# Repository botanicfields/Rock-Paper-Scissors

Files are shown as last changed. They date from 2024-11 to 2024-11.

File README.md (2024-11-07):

# Rock-Paper-Scissors
This is a beginner-friendly craft kit used at DIY events as a material for hands-on soldering.  
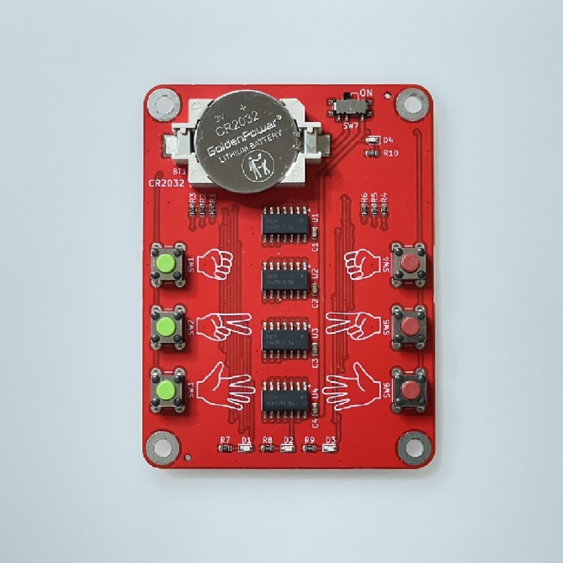
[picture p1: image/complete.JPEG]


# じゃんけん判定器キット
- 初級用のはんだ付け教材を想定した電子工作キットです。  
- 地域イベントなどで、電子工作のはんだ付け体験（ハンズオン）に利用できます。  
- 不特定の来場者が短時間の参加で完成できる様、はんだ付け個所を24と少なくしています。  
- 難易度を下げるため、取り付ける部品はタクトスイッチのみとしています。  
- 安価な部品を使用し、コストを下げています。  

## 注意
- プリント基板やはんだには有毒な重金属(鉛など)が含まれています。
    - 工作した後や遊んだ後は、石鹸で手を洗ってください。
    - 小動物などがかじらない様にご注意ください。
    - 廃棄の際は自治体の指定に従ってください。
- 部品やはんだなどの突起物があります。
    - 部品や突起物に衣類を引っ掛けたり怪我をしないようご注意ください。
    - ケースやカバーを作成される場合は、四隅の穴をご利用ください。
- 小さなお子様には特にご注意ください。
    - プリント基板を舐めたりしない様、ご注意ください。
    - コイン電池などを飲み込まない様、ご注意ください。

## 内容物
- プリント基板(74x56mm, タクトスイッチ以外の部品は実装済) x1
- タクトスイッチ 赤 x3, 緑 x3
- コイン電池 CR2032 x1
- 説明書 x1  
※ケースやカバーは、ありません。  
※組み立てには、はんだ、はんだごてを含む工具が必要です。  
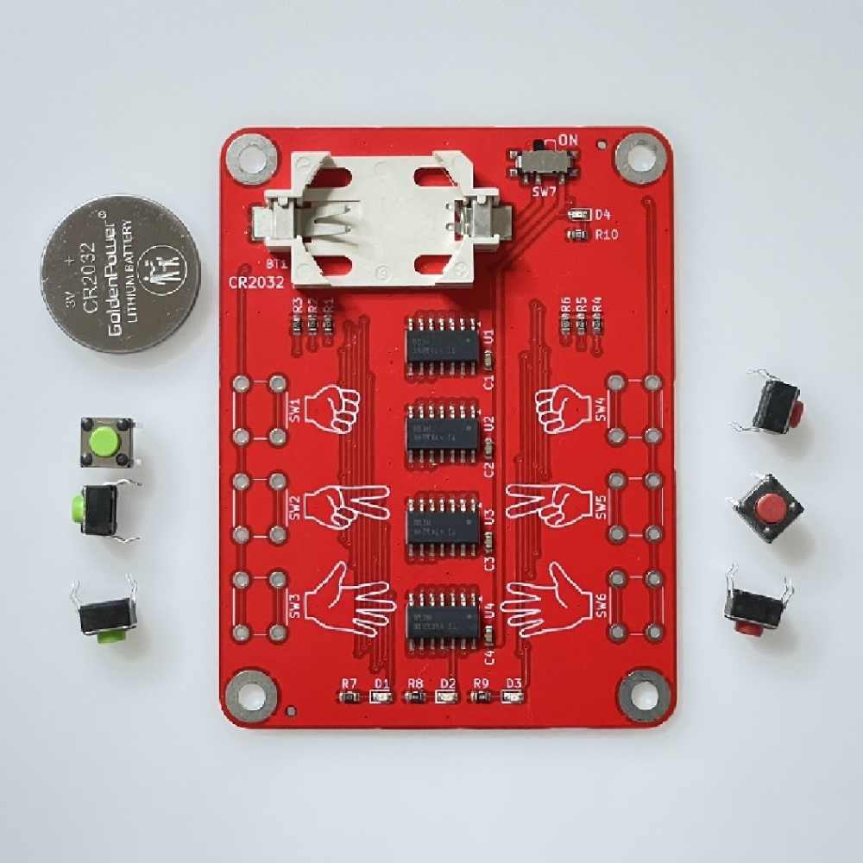
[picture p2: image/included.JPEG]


## 組み立て
### 1. プリント基板にタクトスイッチ6個を挿入します。
(1) 電池ホルダーを奥側に置いたとき、左側3個が緑、右側3個が赤です。  
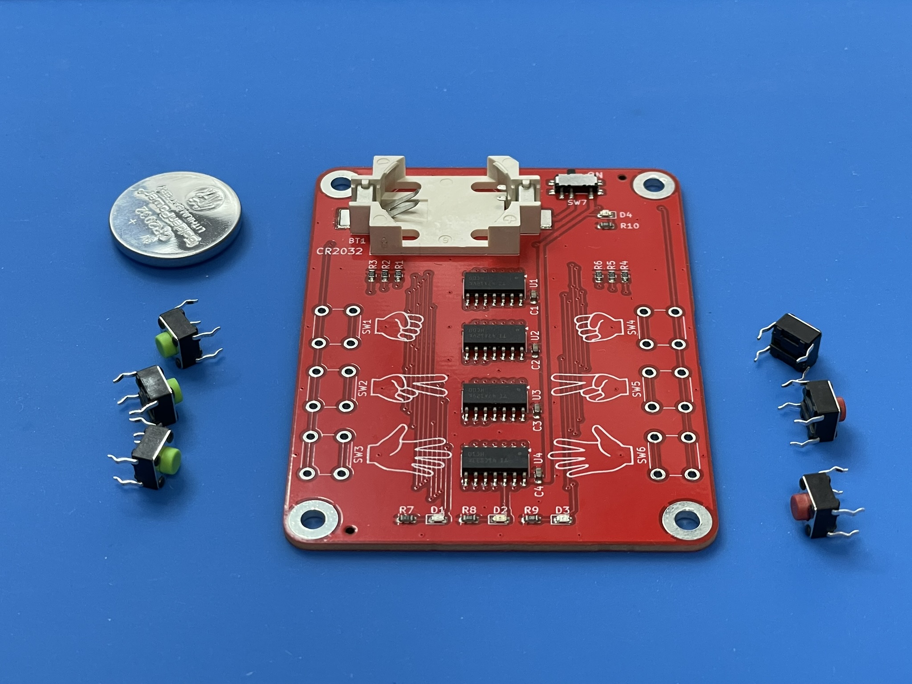
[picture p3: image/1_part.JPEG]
  
(2) タクトスイッチがプリント基板に密着するまでしっかりと挿入します。  
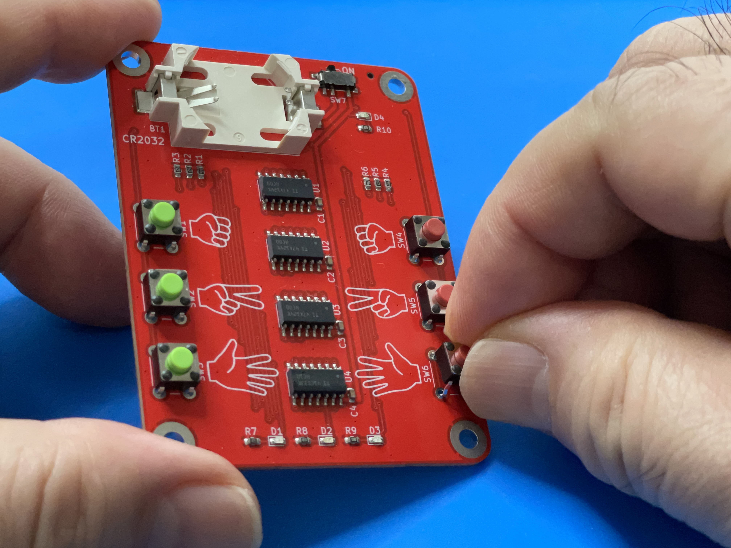
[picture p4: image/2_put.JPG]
  

### 2. はんだ付けします。  
(1) プリント基板を裏返し、タクトスイッチ6個分24個所全てをはんだ付けします。  
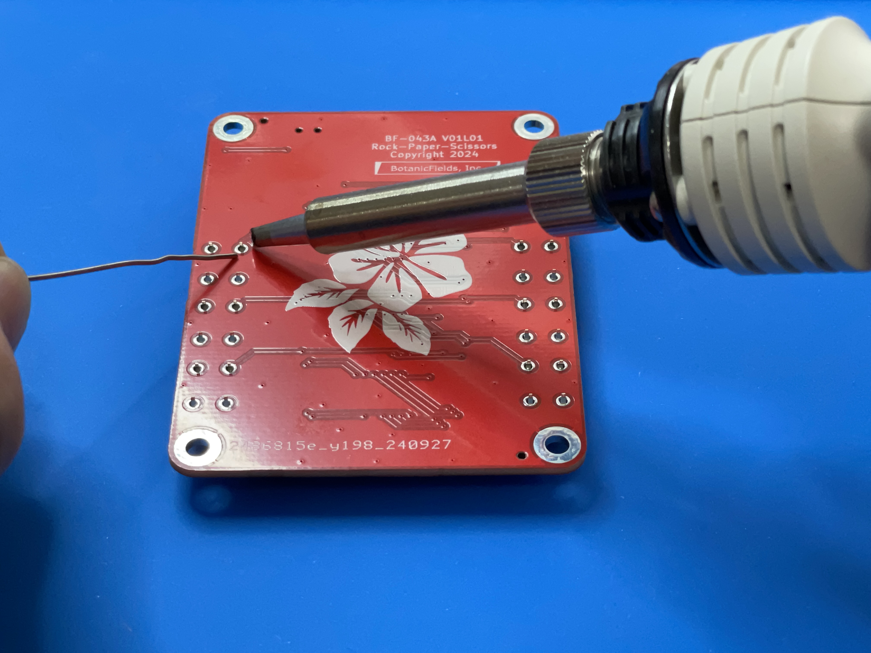
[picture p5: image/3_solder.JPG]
  

### 3. コイン電池(CR2032)を電池ホルダーに取り付けます。  
(1) コイン電池のプラス(+)を上にします。  
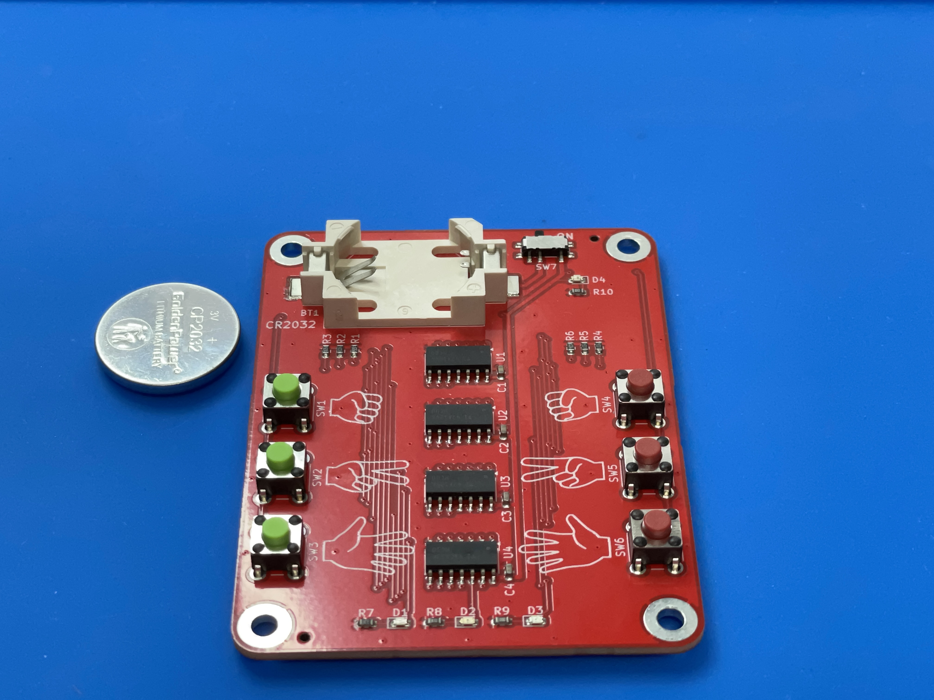
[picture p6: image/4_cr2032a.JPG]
  
(2) 電池ホルダーの、スライドスイッチに近い方の金具に、コイン電池を差し込み引っ掛けます。  
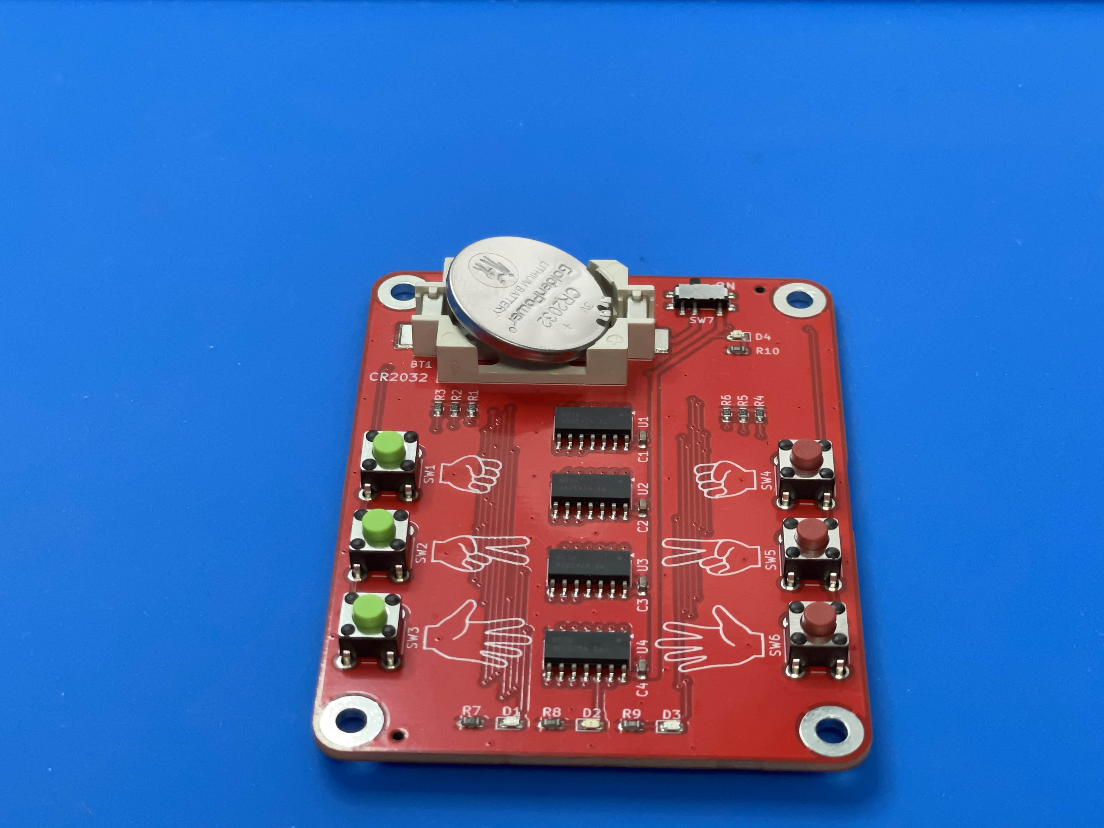
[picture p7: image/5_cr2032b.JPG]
  
(3) コイン電池の、電池ホルダーに引っ掛けた反対側を、押し込みます。  
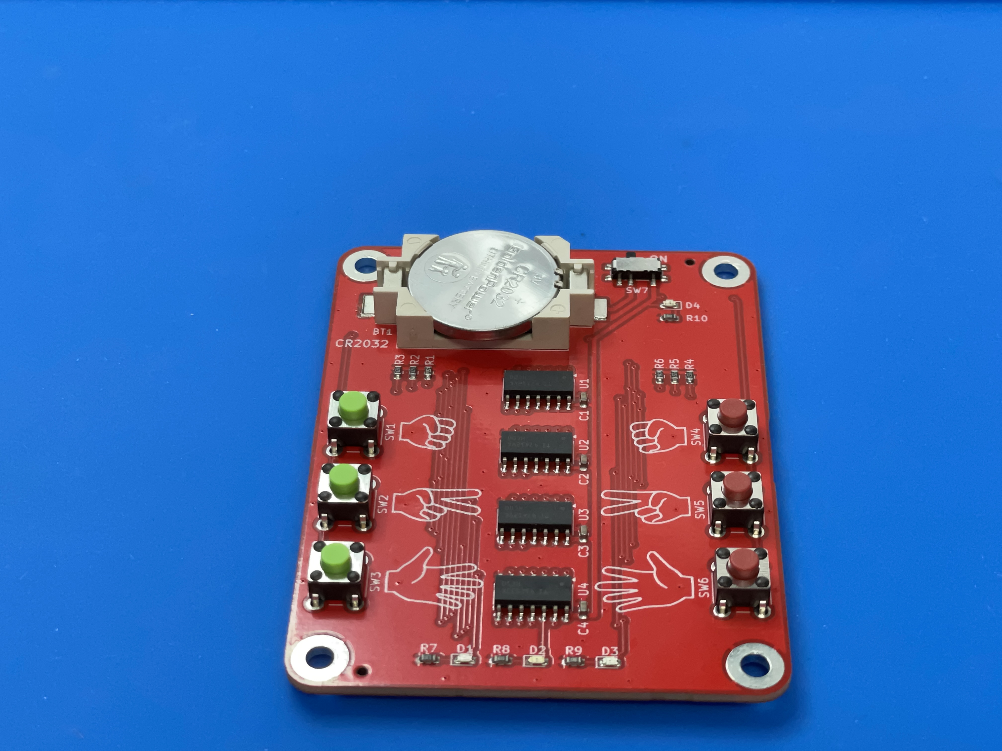
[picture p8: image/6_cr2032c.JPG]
  

## 遊び方
### 1. 電源を入れます。
(1) スライドスイッチをONの位置にします。オレンジ色が点灯します。  
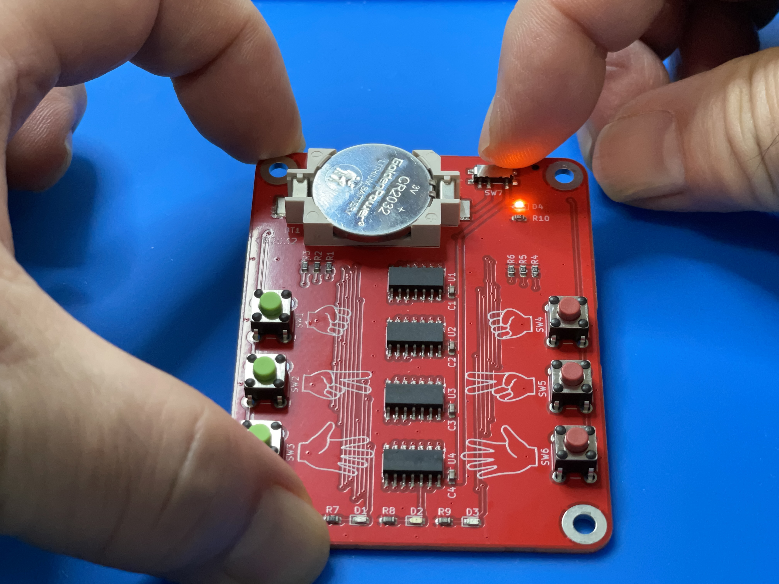
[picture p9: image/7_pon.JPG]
  

### 2. じゃんけんをします。
(1) 赤と緑に分かれて遊びます。  
(2) 「じゃんけんポン！」で、赤の人と緑の人が各々「グー」、「チョキ」、「パー」のボタンのどれかを押します。  
(3) 赤色が点灯すれば赤の勝ち、緑色が点灯すれば緑の勝ち、黄色が点灯すれば「あいこ」です。  
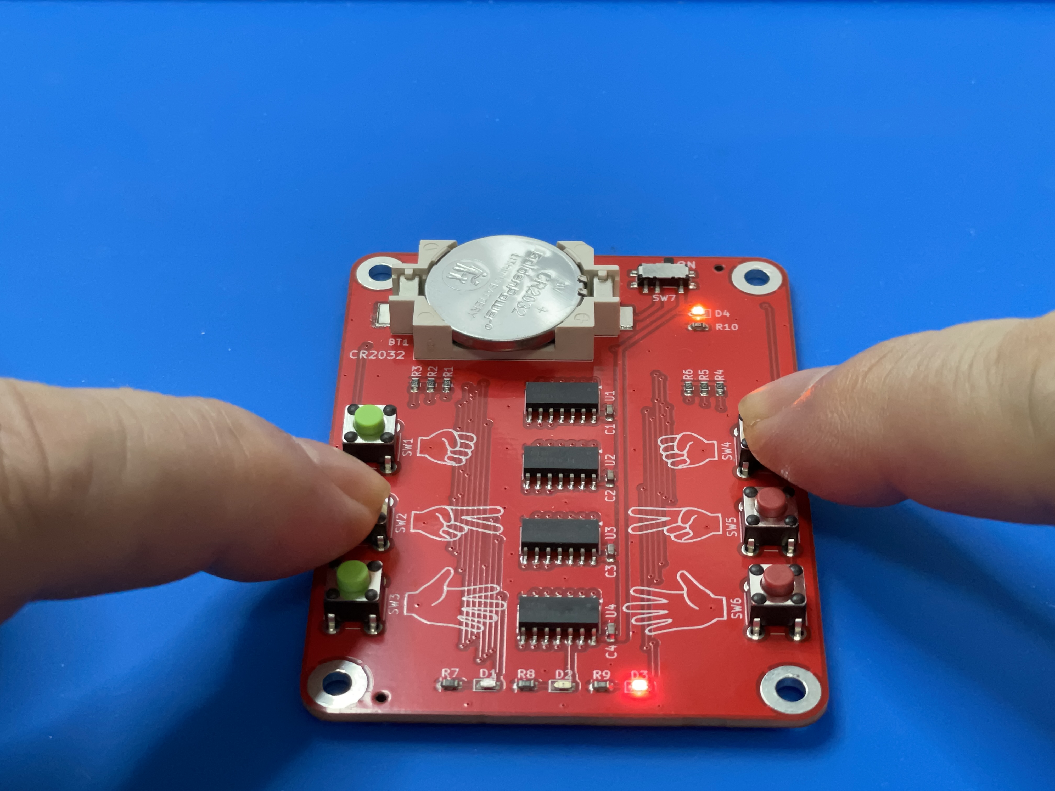
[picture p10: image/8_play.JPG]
  

### 3. 電源を切ります。
(1) 遊び終わったらスライドスイッチをONと反対の位置に戻します。  

## 説明書
- [説明書](./bf-043a_doc.pdf)  

## 回路図
- [回路図](./bf-043a_scm.pdf)  
- コイン電池(3V)で動作するよう74HCシリーズを使用し、Vf=2V程度のLEDを選択しています。
- 入手容易で安価なICを使うため、入力ボタンはハイサイドでプルダウン抵抗付きとし、出力もハイサイドで直接LEDを駆動しています。
- 明るさを合わせるため、緑LEDのみ電流制限抵抗を小さくしています。
- タクトスイッチのみ、はんだ付けハンズオン用にスルーホール部品を使用しています。赤色・緑色も選択できました。

## 実装図
- [実装図](./bf-043a_pcb.pdf)  

## 製造データ
- [KiCadデータ(単体)](./V01L02)  
- [製造データ(面付け12枚)](./V01L02/production)  
- 製造データは、JLCPCB "Fabrication Toolkit" により生成しました。

## ハンズオン開催イベント
- [電波文化祭⚡️サイクル3](https://scrapbox.io/denpa/%E3%83%9C%E3%82%BF%E3%83%8B%E3%83%83%E3%82%AF@%E9%9B%BB%E5%AD%90%E5%B7%A5%E4%BD%9C%E5%A5%BD%E3%81%8D_JK1TZG%E2%9A%A1%EF%B8%8F%E3%82%B5%E3%8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)

以上

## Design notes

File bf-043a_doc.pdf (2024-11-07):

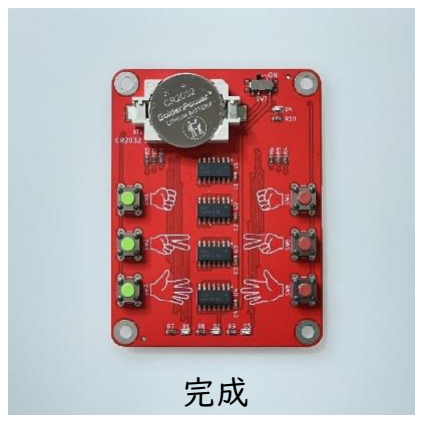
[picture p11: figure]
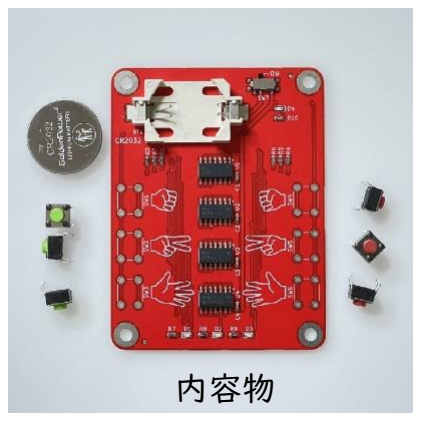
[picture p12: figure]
内容物
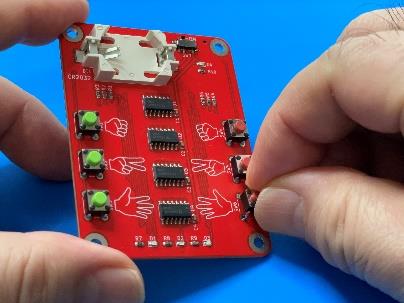
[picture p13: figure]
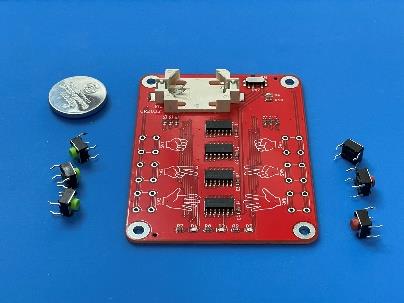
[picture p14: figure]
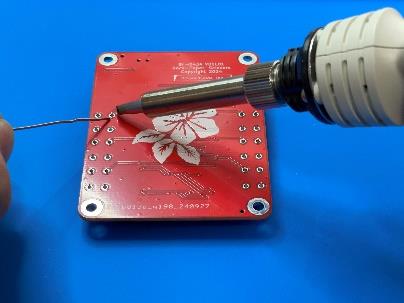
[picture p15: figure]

BF-043A V01 | 1 | Copyright 2024, BotanicFields, Inc.

# じゃんけん判定器キット

初級用のはんだ付け教材を想定した電子工作キットです。

✓ | 地域イベントなどで、はんだ付け体験（ハンズオン）に利用できます。
✓ | 短時間で完成できる様、はんだ付け個所を 24 と少なくしています。
✓ | 難易度を下げるため、はんだ付けはタクトスイッチのみとしています。
1. 内容物

① プリント基板(74x56mm, タクトスイッチ以外の部品は実装済) x1

② タクトスイッチ 赤 x3, 緑 x3

③ コイン電池 CR2032 x1

④ 説明書 x1

※ ケースやカバーは、ありません。

※ 組み立てには、はんだ、はんだごてを含む工具が必要です。

2. ご注意

① プリント基板やはんだには有毒な重金属(鉛など)が含まれています。

- 工作した後や遊んだ後は、石鹸で手を洗ってください。
- 小動物などがかじらない様にご注意ください。
- 廃棄の際は自治体の指定に従ってください。

② 部品やはんだなどの突起物があります。

- 部品や突起物に衣類を引っ掛けたり怪我をしないようご注意ください。
- ケースやカバーを作成される場合は、四隅の穴をご利用ください。

③ 小さなお子様には特にご注意ください。

- プリント基板を舐めたりしない様、ご注意ください。
- コイン電池などを飲み込まない様、ご注意ください。
3. 組み立て

① プリント基板にタクトスイッチ 6 個を挿入します。

- 電池ホルダーを奥側に置いたとき、左側 3 個が緑、右側 3 個が赤です。
- タクトスイッチがプリント基板に密着するまでしっかりと挿入します。

② はんだ付けします。

- プリント基板を裏返し、タクトスイッチ 6 個分 24 個所全てをはんだ付けします。

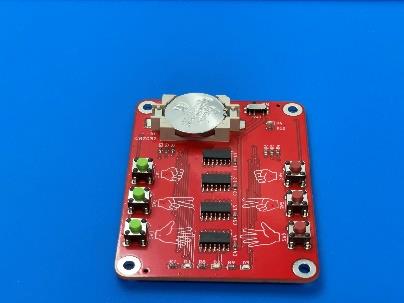
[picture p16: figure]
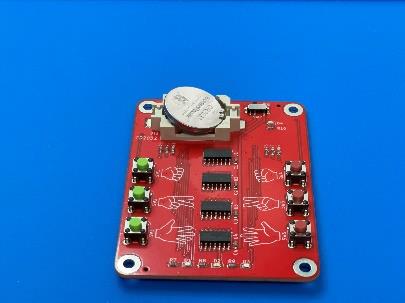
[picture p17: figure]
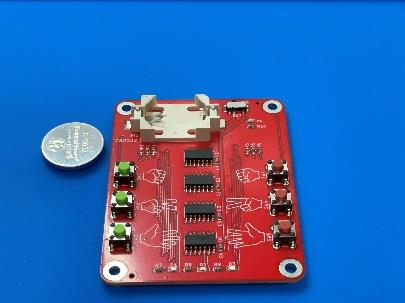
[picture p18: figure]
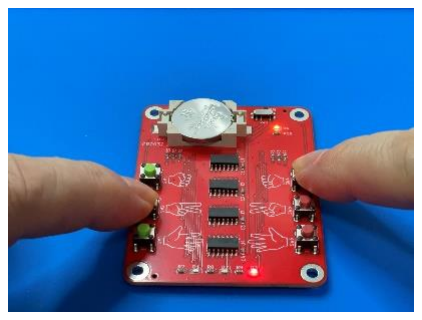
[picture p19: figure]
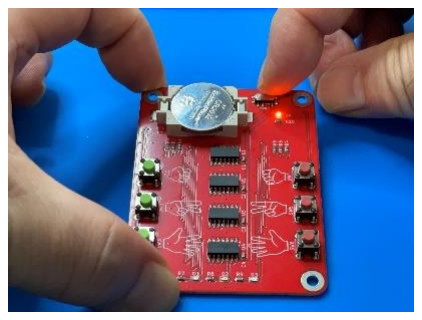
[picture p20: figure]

BF-043A V01 | 2 | Copyright 2024, BotanicFields, Inc.

③ コイン電池(CR2032)を電池ホルダーに取り付けます。

- コイン電池のプラス(+)を上にします。
- 電池ホルダーの、スライドスイッチに近い方の金具に、コイン電池を差し込み引っ掛けます。
- コイン電池の、電池ホルダーに引っ掛けた反対側を、押し込みます。
4. 遊び方

① 電源を入れます。

- スライドスイッチを ON の位置にします。オレンジ色が点灯します。

② じゃんけんをします。

- 赤と緑に分かれて遊びます。
- 「じゃんけんポン！」で、赤の人と緑の人が各々「グー」、「チョキ」、「パー」のボタンのどれか

を押します。

- 赤色が点灯すれば赤の勝ち、緑色が点灯すれば緑の勝ち、黄色が点灯すれば「あいこ」です。

③ 電源を切ります。

- 遊び終わったらスライドスイッチを ON と反対の位置に戻します。
5. 詳細情報

回路図、実装図、設計データ、その他の最新情報については、以下をご参照ください。

https://github.com/botanicfields/Rock-Paper-Scissors

以上

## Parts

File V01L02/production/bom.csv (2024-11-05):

Designator | Footprint | Quantity | Value | LCSC Part #
BT1_12, BT1_11, BT1_10, BT1_9, BT1_8, BT1_7, BT1_6, BT1_5, BT1_4, BT1_3, BT1_2, BT1 | BF@QJ-BS-6 | 12 | CR2032 | C70377
C1_12, C1_11, C1_10, C1_9, C1_8, C1_7, C1_6, C1_5, C1_4, C1_3, C1_2, C1, C2_12, C2_11, C2_10, C2_9, C2_8, C2_7, C2_6, C2_5, C2_4, C2_3, C2_2, C2, C3_12, C3_11, C3_10, C3_9, C3_8, C3_7, C3_6, C3_5, C3_4, C3_3, C3_2, C3, C4_12, C4_11, C4_10, C4_9, C4_8, C4_7, C4_6, C4_5, C4_4, C4_3, C4_2, C4 | 0603 | 48 | 100n | C14663
D1_12, D1_11, D1_10, D1_9, D1_8, D1_7, D1_6, D1_5, D1_4, D1_3, D1_2, D1 | 0603 | 12 | A-Win | C965805
D2_12, D2_11, D2_10, D2_9, D2_8, D2_7, D2_6, D2_5, D2_4, D2_3, D2_2, D2 | 0603 | 12 | Draw | C72038
D3_12, D3_11, D3_10, D3_9, D3_8, D3_7, D3_6, D3_5, D3_4, D3_3, D3_2, D3 | 0603 | 12 | B-Win | C2286
D4_12, D4_11, D4_10, D4_9, D4_8, D4_7, D4_6, D4_5, D4_4, D4_3, D4_2, D4 | 0603 | 12 | Pilot | C7429913
KiKit_MB_10_2, KiKit_MB_10_3, KiKit_MB_10_4, KiKit_MB_10_5, KiKit_MB_10_6, KiKit_MB_10_7, KiKit_MB_10_8, KiKit_MB_10_9, KiKit_MB_11_2, KiKit_MB_11_3, KiKit_MB_11_4, KiKit_MB_11_5, KiKit_MB_11_6, KiKit_MB_11_7, KiKit_MB_11_8, KiKit_MB_11_9, KiKit_MB_12_2, KiKit_MB_12_3, KiKit_MB_12_4, KiKit_MB_12_5, KiKit_MB_12_6, KiKit_MB_12_7, KiKit_MB_12_8, KiKit_MB_12_9, KiKit_MB_13_2, KiKit_MB_13_3, KiKit_MB_13_4, KiKit_MB_13_5, KiKit_MB_13_6, KiKit_MB_13_7, KiKit_MB_13_8, KiKit_MB_13_9, KiKit_MB_14_2, KiKit_MB_14_3, KiKit_MB_14_4, KiKit_MB_14_5, KiKit_MB_14_6, KiKit_MB_14_7, KiKit_MB_14_8, KiKit_MB_14_9, KiKit_MB_15_2, KiKit_MB_15_3, KiKit_MB_15_4, KiKit_MB_15_5, KiKit_MB_15_6, KiKit_MB_15_7, KiKit_MB_15_8, KiKit_MB_15_9, KiKit_MB_16_2, KiKit_MB_16_3, KiKit_MB_16_4, KiKit_MB_16_5, KiKit_MB_16_6, KiKit_MB_16_7, KiKit_MB_16_8, KiKit_MB_16_9, KiKit_MB_17_2, KiKit_MB_17_3, KiKit_MB_17_4, KiKit_MB_17_5, KiKit_MB_17_6, KiKit_MB_17_7, KiKit_MB_17_8, KiKit_MB_17_9, KiKit_MB_18_2, KiKit_MB_18_3, KiKit_MB_18_4, KiKit_MB_18_5, KiKit_MB_18_6, KiKit_MB_18_7, KiKit_MB_18_8, KiKit_MB_18_9, KiKit_MB_19_2, KiKit_MB_19_3, KiKit_MB_19_4, KiKit_MB_19_5, KiKit_MB_19_6, KiKit_MB_19_7, KiKit_MB_19_8, KiKit_MB_19_9, KiKit_MB_1_2, KiKit_MB_1_3, KiKit_MB_1_4, KiKit_MB_1_5, KiKit_MB_1_6, KiKit_MB_1_7, KiKit_MB_1_8, KiKit_MB_1_9, KiKit_MB_20_2, KiKit_MB_20_3, KiKit_MB_20_4, KiKit_MB_20_5, KiKit_MB_20_6, KiKit_MB_20_7, KiKit_MB_20_8, KiKit_MB_20_9, KiKit_MB_21_2, KiKit_MB_21_3, KiKit_MB_21_4, KiKit_MB_21_5, KiKit_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 | NPTH | 200 | NPTH
KiKit_MB_33_2, KiKit_MB_33_3, KiKit_MB_33_4, KiKit_MB_33_5, KiKit_MB_33_6, KiKit_MB_33_7, KiKit_MB_33_8, KiKit_MB_33_9, KiKit_MB_34_2, KiKit_MB_34_3, KiKit_MB_34_4, KiKit_MB_34_5, KiKit_MB_34_6, KiKit_MB_34_7, KiKit_MB_34_8, KiKit_MB_34_9, KiKit_MB_35_2, KiKit_MB_35_3, KiKit_MB_35_4, KiKit_MB_35_5, KiKit_MB_35_6, KiKit_MB_35_7, KiKit_MB_35_8, KiKit_MB_35_9, KiKit_MB_36_2, KiKit_MB_36_3, KiKit_MB_36_4, KiKit_MB_36_5, KiKit_MB_36_6, KiKit_MB_36_7, KiKit_MB_36_8, KiKit_MB_36_9, KiKit_MB_37_2, KiKit_MB_37_3, KiKit_MB_37_4, KiKit_MB_37_5, KiKit_MB_37_6, KiKit_MB_37_7, KiKit_MB_37_8, KiKit_MB_37_9, KiKit_MB_38_2, KiKit_MB_38_3, KiKit_MB_38_4, KiKit_MB_38_5, KiKit_MB_38_6, KiKit_MB_38_7, KiKit_MB_38_8, KiKit_MB_38_9, KiKit_MB_39_2, KiKit_MB_39_3, KiKit_MB_39_4, KiKit_MB_39_5, KiKit_MB_39_6, KiKit_MB_39_7, KiKit_MB_39_8, KiKit_MB_39_9, KiKit_MB_3_2, KiKit_MB_3_3, KiKit_MB_3_4, KiKit_MB_3_5, KiKit_MB_3_6, KiKit_MB_3_7, KiKit_MB_3_8, KiKit_MB_3_9, KiKit_MB_40_2, KiKit_MB_40_3, KiKit_MB_40_4, KiKit_MB_40_5, KiKit_MB_40_6, KiKit_MB_40_7, KiKit_MB_40_8, KiKit_MB_40_9, KiKit_MB_41_2, KiKit_MB_41_3, KiKit_MB_41_4, KiKit_MB_41_5, KiKit_MB_41_6, KiKit_MB_41_7, KiKit_MB_41_8, KiKit_MB_41_9, KiKit_MB_42_2, KiKit_MB_42_3, KiKit_MB_42_4, KiKit_MB_42_5, KiKit_MB_42_6, KiKit_MB_42_7, KiKit_MB_42_8, KiKit_MB_42_9, KiKit_MB_43_2, KiKit_MB_43_3, KiKit_MB_43_4, KiKit_MB_43_5, KiKit_MB_43_6, KiKit_MB_43_7, KiKit_MB_43_8, KiKit_MB_43_9, KiKit_MB_44_2, KiKit_MB_44_3, KiKit_MB_44_4, KiKit_MB_44_5, KiKit_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 | NPTH | 200 | NPTH
KiKit_MB_9_2, KiKit_MB_9_3, KiKit_MB_9_4, KiKit_MB_9_5, KiKit_MB_9_6, KiKit_MB_9_7, KiKit_MB_9_8, KiKit_MB_9_9 | NPTH | 8 | NPTH
R1_12, R1_11, R1_10, R1_9, R1_8, R1_7, R1_6, R1_5, R1_4, R1_3, R1_2, R1, R2_12, R2_11, R2_10, R2_9, R2_8, R2_7, R2_6, R2_5, R2_4, R2_3, R2_2, R2, R3_12, R3_11, R3_10, R3_9, R3_8, R3_7, R3_6, R3_5, R3_4, R3_3, R3_2, R3, R4_12, R4_11, R4_10, R4_9, R4_8, R4_7, R4_6, R4_5, R4_4, R4_3, R4_2, R4, R5_12, R5_11, R5_10, R5_9, R5_8, R5_7, R5_6, R5_5, R5_4, R5_3, R5_2, R5, R6_12, R6_11, R6_10, R6_9, R6_8, R6_7, R6_6, R6_5, R6_4, R6_3, R6_2, R6 | 0603 | 72 | 4.7k | C23162
R10_12, R10_11, R10_10, R10_9, R10_8, R10_7, R10_6, R10_5, R10_4, R10_3, R10_2, R10, R8_12, R8_11, R8_10, R8_9, R8_8, R8_7, R8_6, R8_5, R8_4, R8_3, R8_2, R8, R9_12, R9_11, R9_10, R9_9, R9_8, R9_7, R9_6, R9_5, R9_4, R9_3, R9_2, R9 | 0603 | 36 | 1k | C21190
R7_12, R7_11, R7_10, R7_9, R7_8, R7_7, R7_6, R7_5, R7_4, R7_3, R7_2, R7 | 0603 | 12 | 330 | C23138
SW1_12, SW1_11, SW1_10, SW1_9, SW1_8, SW1_7, SW1_6, SW1_5, SW1_4, SW1_3, SW1_2, SW1, SW4_12, SW4_11, SW4_10, SW4_9, SW4_8, SW4_7, SW4_6, SW4_5, SW4_4, SW4_3, SW4_2, SW4 | SW_PUSH_6mm_H5mm | 24 | Rock
SW2_12, SW2_11, SW2_10, SW2_9, SW2_8, SW2_7, SW2_6, SW2_5, SW2_4, SW2_3, SW2_2, SW2, SW5_12, SW5_11, SW5_10, SW5_9, SW5_8, SW5_7, SW5_6, SW5_5, SW5_4, SW5_3, SW5_2, SW5 | SW_PUSH_6mm_H5mm | 24 | Scissors
SW3_12, SW3_11, SW3_10, SW3_9, SW3_8, SW3_7, SW3_6, SW3_5, SW3_4, SW3_3, SW3_2, SW3, SW6_12, SW6_11, SW6_10, SW6_9, SW6_8, SW6_7, SW6_6, SW6_5, SW6_4, SW6_3, SW6_2, SW6 | SW_PUSH_6mm_H5mm | 24 | Paper
SW7_12, SW7_11, SW7_10, SW7_9, SW7_8, SW7_7, SW7_6, SW7_5, SW7_4, SW7_3, SW7_2, SW7 | SW_SPDT_PCM12 | 12 | Power | C109335
U1_12, U1_11, U1_10, U1_9, U1_8, U1_7, U1_6, U1_5, U1_4, U1_3, U1_2, U1, U2_12, U2_11, U2_10, U2_9, U2_8, U2_7, U2_6, U2_5, U2_4, U2_3, U2_2, U2, U3_12, U3_11, U3_10, U3_9, U3_8, U3_7, U3_6, U3_5, U3_4, U3_3, U3_2, U3 | SO-14_3.9x8.65mm_P1.27mm | 36 | 74HC00 | C10090
U4_12, U4_11, U4_10, U4_9, U4_8, U4_7, U4_6, U4_5, U4_4, U4_3, U4_2, U4 | SO-14_3.9x8.65mm_P1.27mm | 12 | 74HC10 | C6816

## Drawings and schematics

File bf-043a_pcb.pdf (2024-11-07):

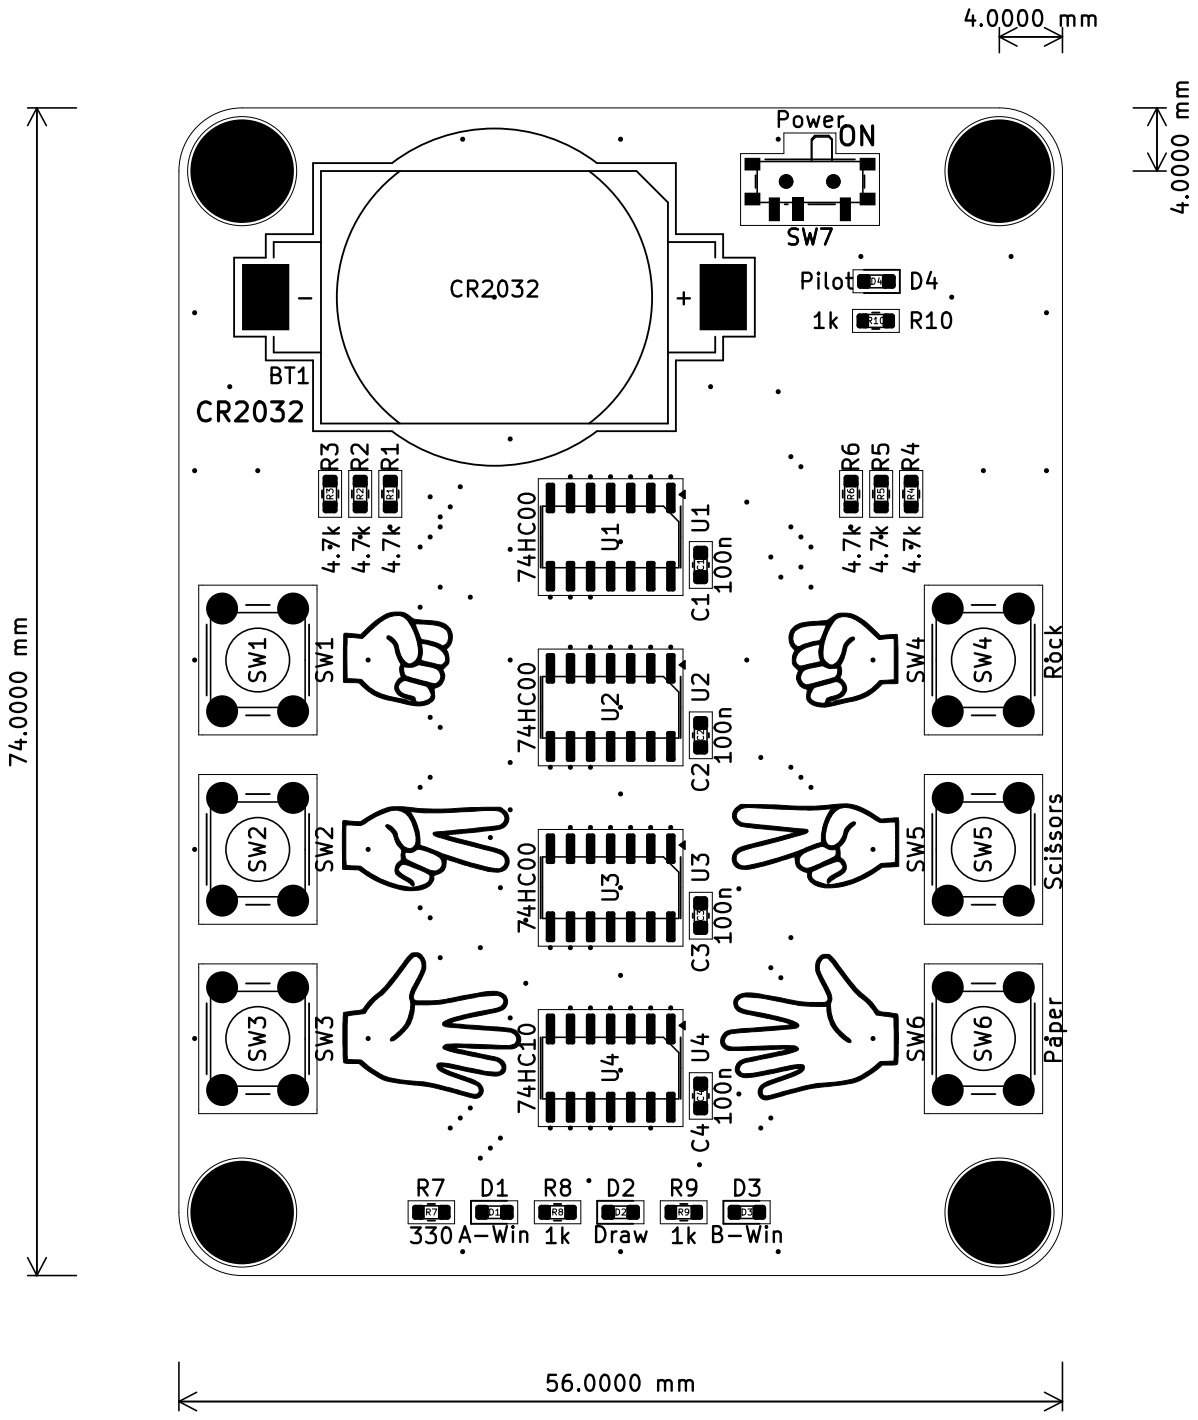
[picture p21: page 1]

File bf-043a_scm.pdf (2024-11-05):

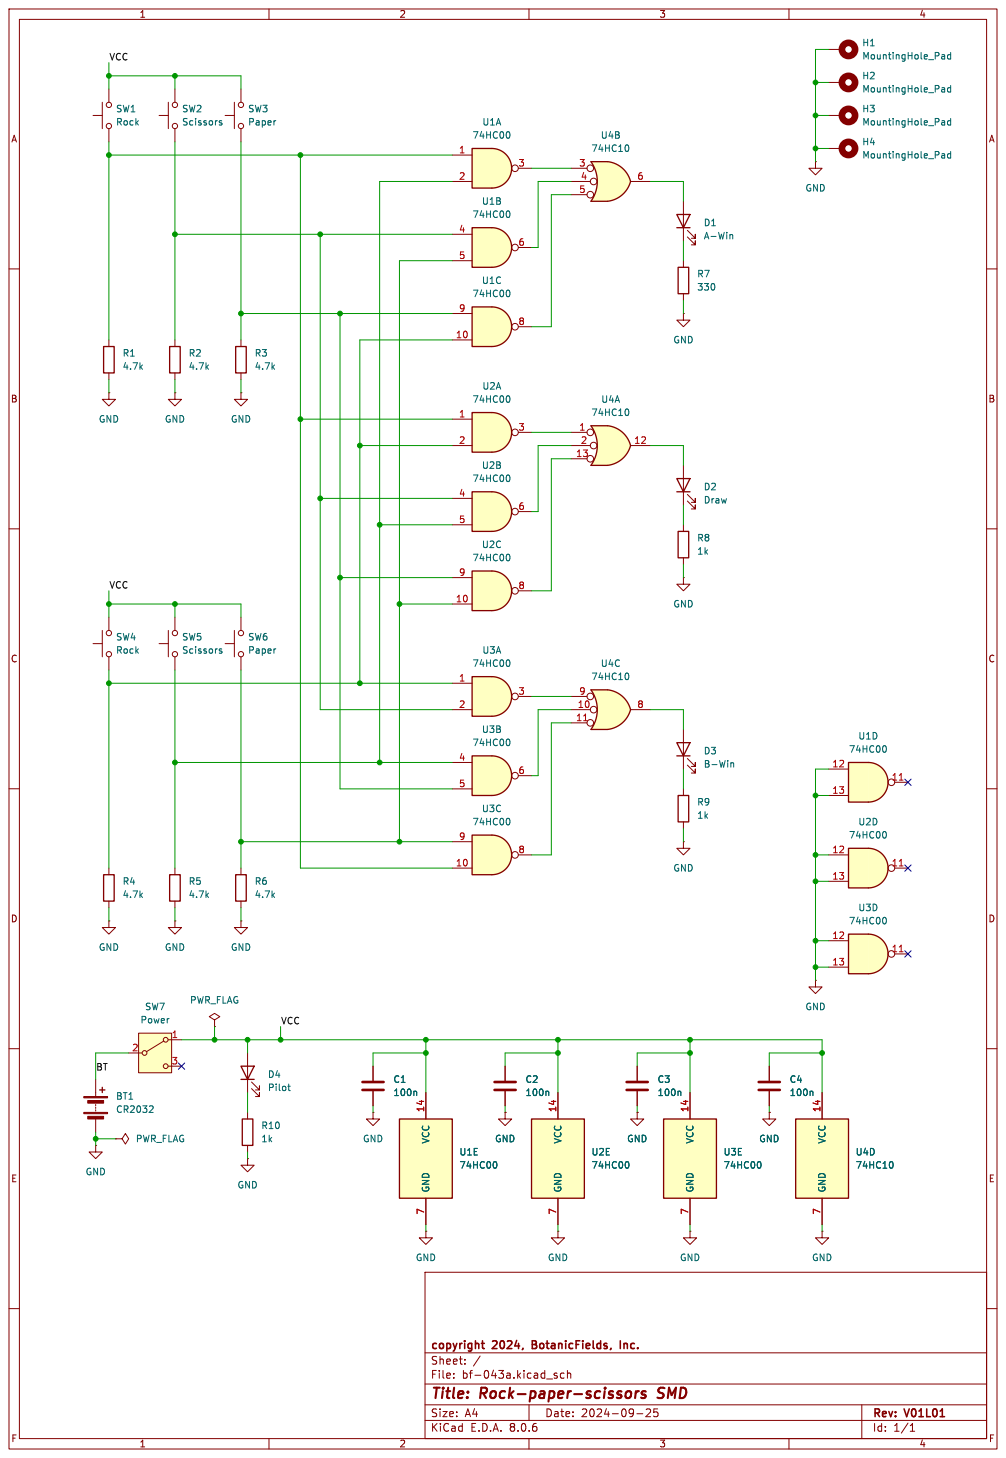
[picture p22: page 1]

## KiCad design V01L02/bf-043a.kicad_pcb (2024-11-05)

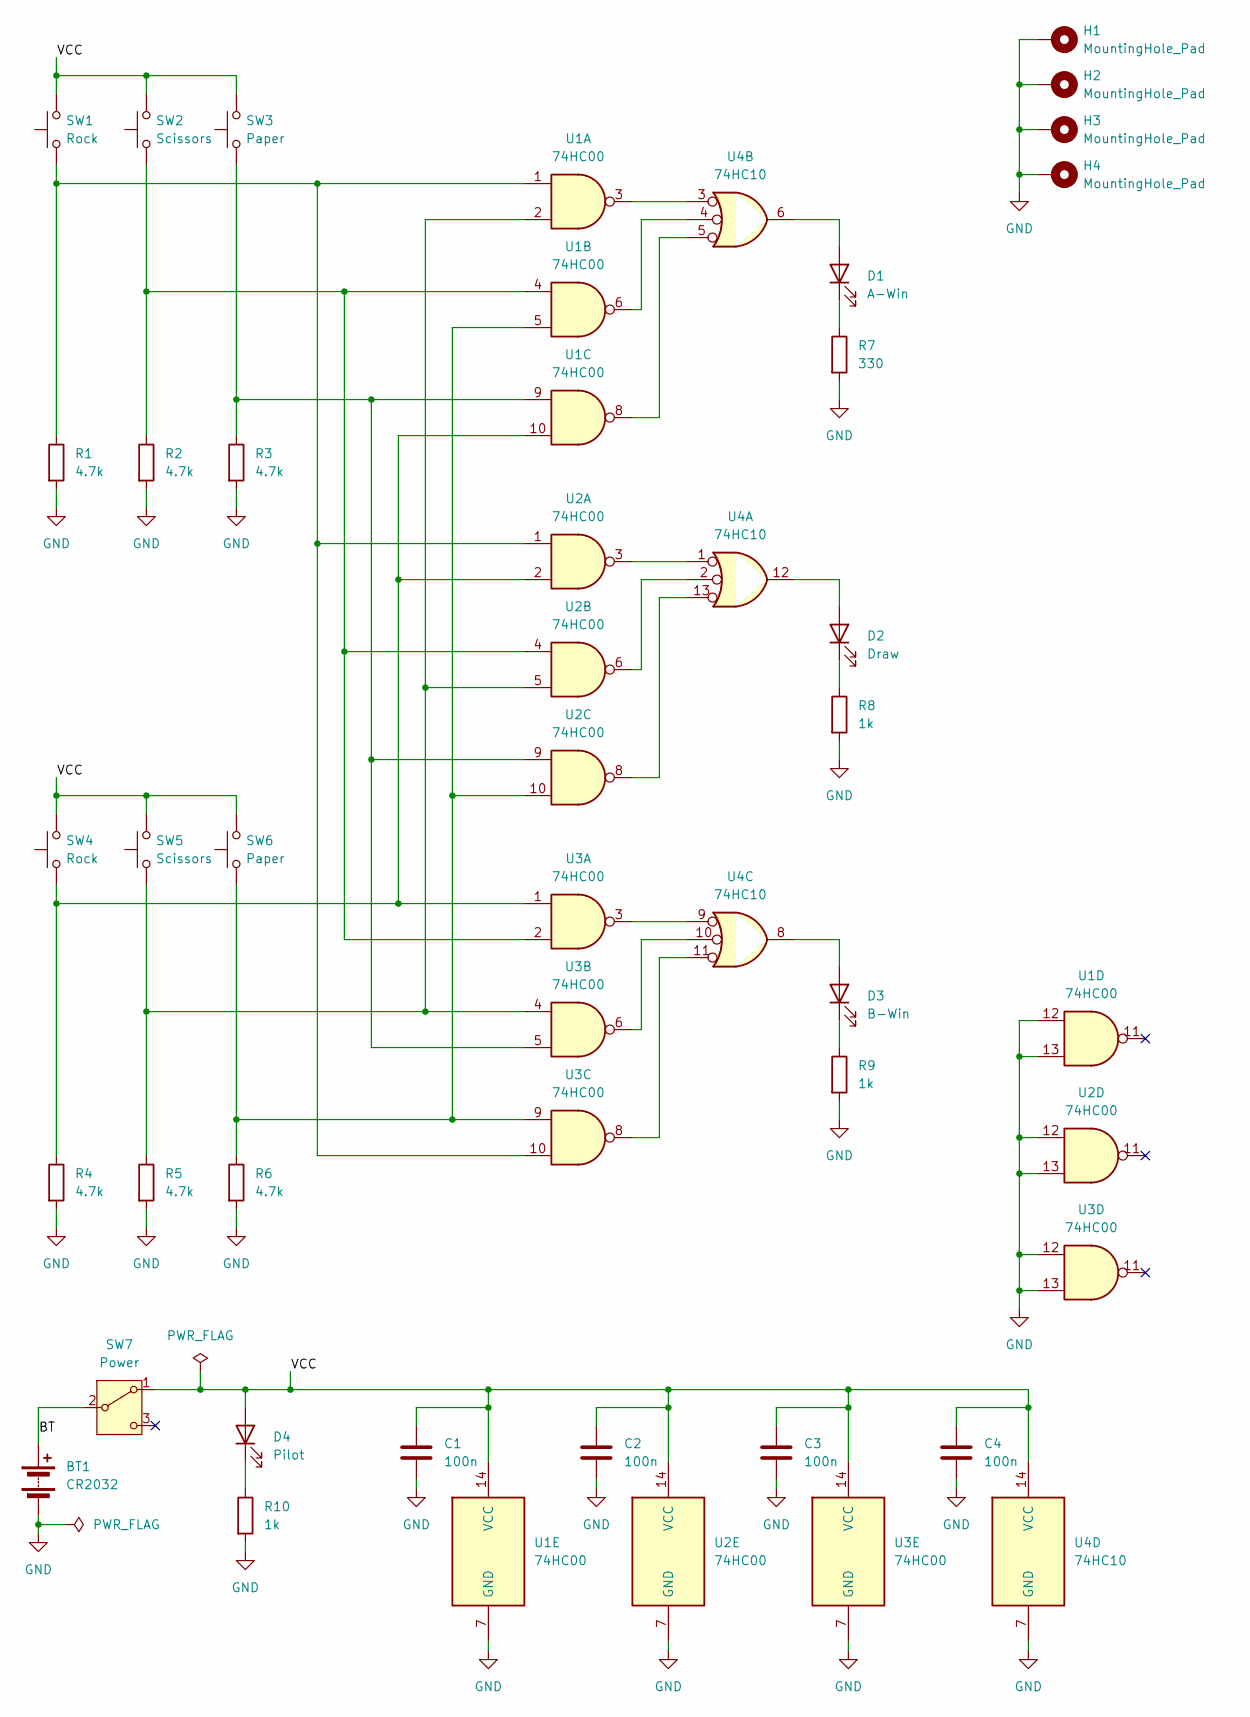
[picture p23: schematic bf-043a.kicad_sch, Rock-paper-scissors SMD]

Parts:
BT1: CR2032; BF@QJ-BS-6
C1, C2, C3, C4: 100n; C_0603_1608Metric
D1: A-Win; LED_0603_1608Metric
D2: Draw; LED_0603_1608Metric
D3: B-Win; LED_0603_1608Metric
D4: Pilot; LED_0603_1608Metric
H1, H2, H3, H4: MountingHole_Pad; MountingHole_3.2mm_M3_Pad
R1, R2, R3, R4, R5, R6: 4.7k; R_0603_1608Metric
R7: 330; R_0603_1608Metric
R8, R9, R10: 1k; R_0603_1608Metric
SW1, SW4: Rock; SW_PUSH_6mm_H5mm
SW2, SW5: Scissors; SW_PUSH_6mm_H5mm
SW3, SW6: Paper; SW_PUSH_6mm_H5mm
SW7: Power; SW_SPDT_PCM12
U1, U2, U3: 74HC00; SO-14_3.9x8.65mm_P1.27mm
U4: 74HC10; SO-14_3.9x8.65mm_P1.27mm

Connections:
/BT: BT1.1 (+), SW7.2 (B)
/VCC: C1.1, C2.1, C3.1, C4.1, D4.2 (A), SW1.2, SW2.2, SW3.2, SW4.2, SW5.2, SW6.2, SW7.1 (A), U1.14 (VCC), U2.14 (VCC), U3.14 (VCC), U4.14 (VCC)
GND: BT1.2 (-), C1.2, C2.2, C3.2, C4.2, H1.1, H2.1, H3.1, H4.1, R1.2, R2.2, R3.2, R4.2, R5.2, R6.2, R7.2, R8.2, R9.2, R10.2, U1.7 (GND), U1.12, U1.13, U2.7 (GND), U2.12, U2.13, U3.7 (GND), U3.12, U3.13, U4.7 (GND)
unnamed: D1.2 (A), U4.6
unnamed: D1.1 (K), R7.1
unnamed: D2.2 (A), U4.12
unnamed: D2.1 (K), R8.1
unnamed: D3.2 (A), U4.8
unnamed: D3.1 (K), R9.1
unnamed: D4.1 (K), R10.1
unnamed: R1.1, SW1.1, U1.1, U2.1, U3.10
unnamed: R2.1, SW2.1, U1.4, U2.4, U3.2
unnamed: R3.1, SW3.1, U1.9, U2.9, U3.5
unnamed: R4.1, SW4.1, U1.10, U2.2, U3.1
unnamed: R5.1, SW5.1, U1.2, U2.5, U3.4
unnamed: R6.1, SW6.1, U1.5, U2.10, U3.9
unnamed: U1.3, U4.3
unnamed: U1.6, U4.4
unnamed: U1.8, U4.5
unnamed: U2.3, U4.1
unnamed: U2.6, U4.2
unnamed: U2.8, U4.13
unnamed: U3.3, U4.9
unnamed: U3.6, U4.10
unnamed: U3.8, U4.11

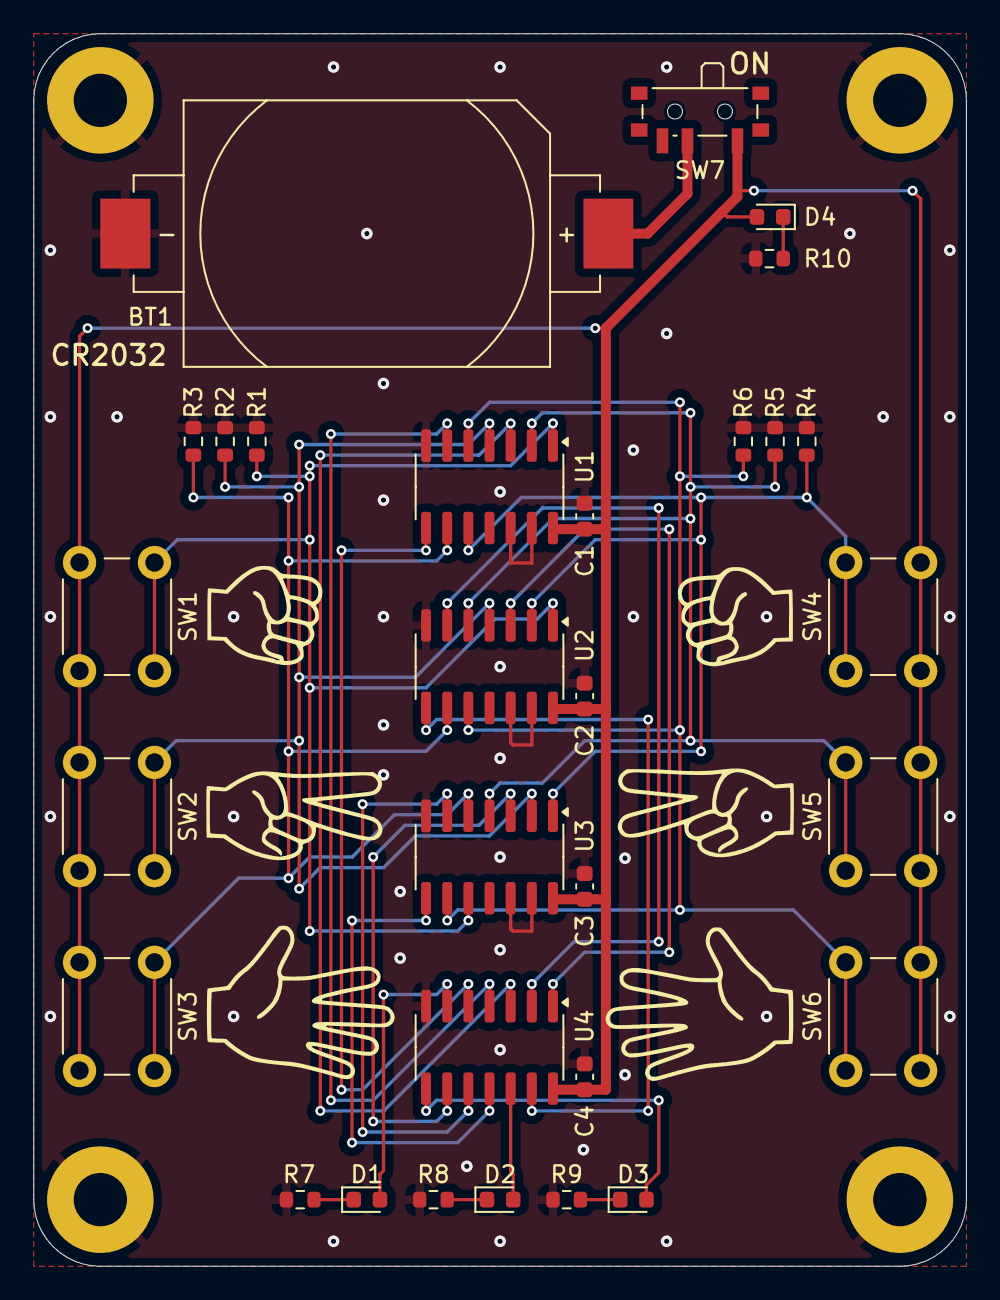
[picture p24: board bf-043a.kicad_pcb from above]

Board: 2 copper layers, 56.0 x 74.0 mm, 34 parts (0 on the bottom side), 25 nets.

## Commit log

2024-11-05 .gitignore, .csv removed
    [bom.csv, designators.csv, positions.csv]
2024-11-05 add comment of fabrication data
    [designators.csv]
